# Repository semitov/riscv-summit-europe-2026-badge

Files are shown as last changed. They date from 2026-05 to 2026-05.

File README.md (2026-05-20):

# RISC-V Summit Europe 2026 Badge

Electronic badge PCB for RISC-V Summit Europe 2026 in Bologna, Italy. Designed in KiCad 10.

## Gallery

- Render of the badge on KiCad
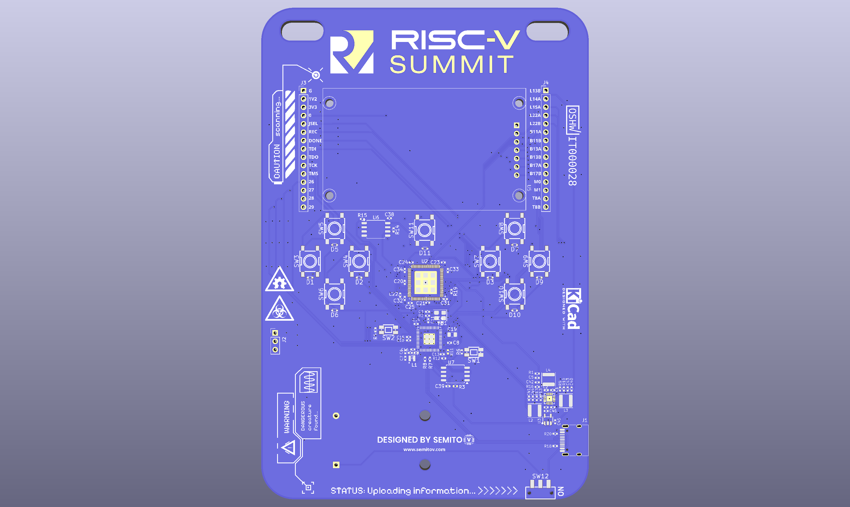
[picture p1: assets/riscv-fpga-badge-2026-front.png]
  
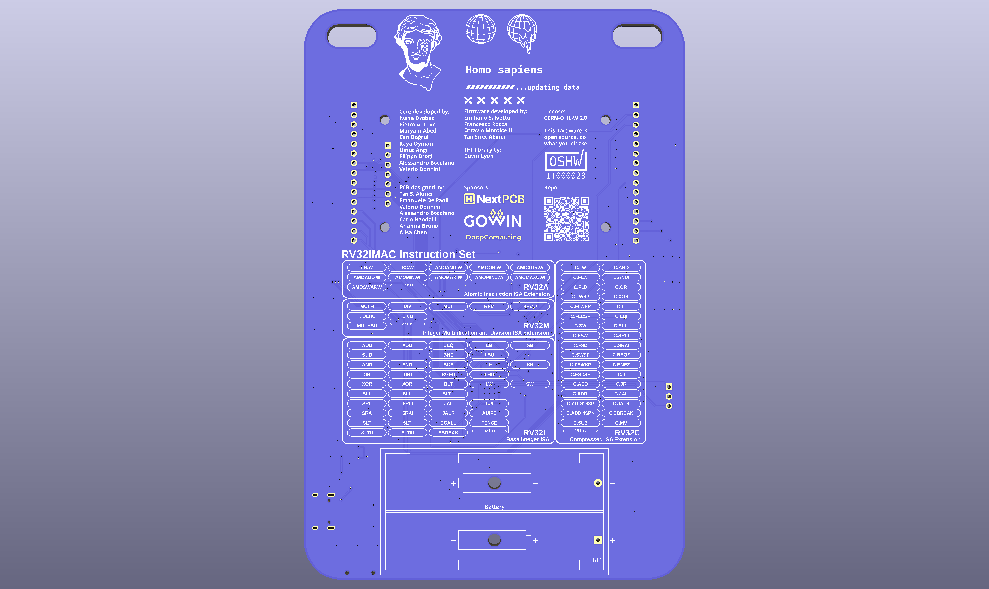
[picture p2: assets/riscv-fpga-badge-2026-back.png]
  

## License and Credits
Designed by: [Tan Siret Akıncı](https://github.com/tansiret), [Emanuele De Paoli](https://github.com/Irdyad), [Carlo Bendelli](https://github.com/CALIOSTRO7), [Valerio Donnini](https://github.com/Valerio-Donnini) and [Alessandro Bocchino](https://github.com/AleB-04).
This open source hardware project is licensed with [CERN-OHL-W](LICENSE). The project is sponsored by © 2026 [RISC-V International](), [NextPCB](https://www.nextpcb.com/), [GOWIN Semiconductor](https://www.gowinsemi.com/en/) and  [DeepComputing](https://deepcomputing.io/).
The project has been certified by [OSHWA](https://oshwa.org/) as Open Source Hardware (UID: [IT000028](https://certification.oshwa.org/it000028.html)).
</br>
<a href="https://certification.oshwa.org/it000028.html">
   
</a>

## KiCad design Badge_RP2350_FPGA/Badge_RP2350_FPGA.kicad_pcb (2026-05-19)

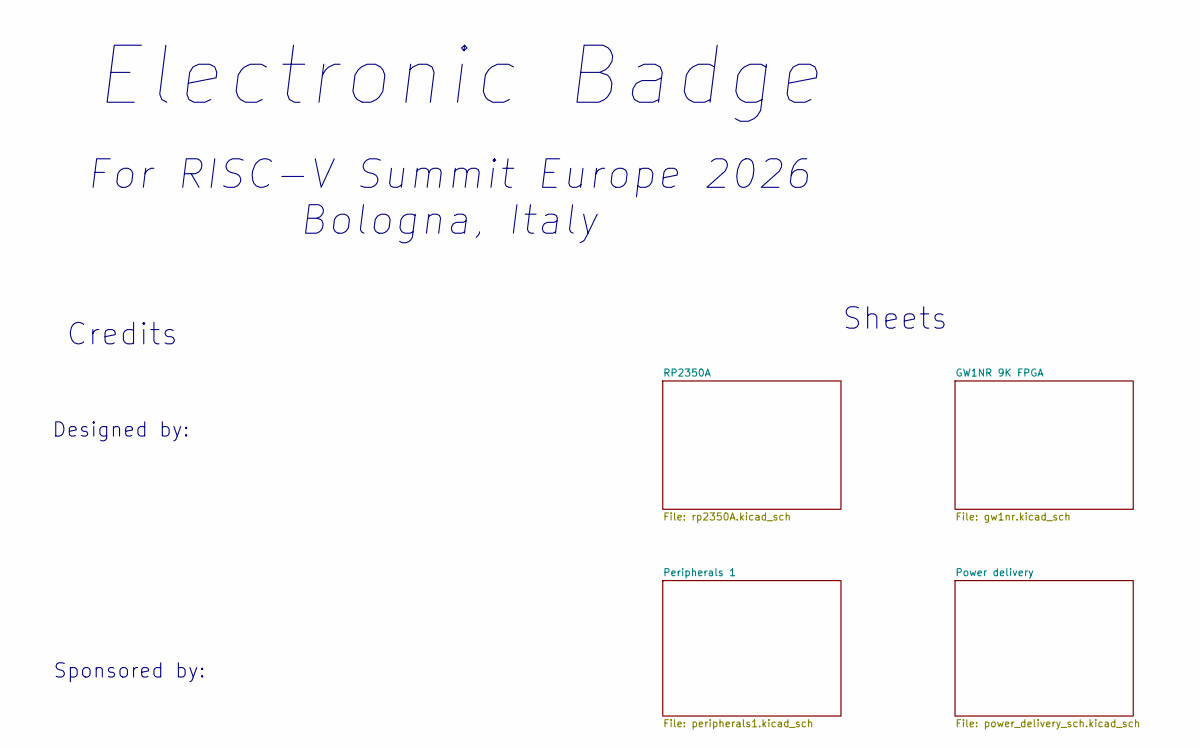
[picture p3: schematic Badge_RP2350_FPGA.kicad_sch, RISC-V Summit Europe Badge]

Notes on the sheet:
Sheets
Credits
Electronic Badge
Sponsored by:
For RISC-V Summit Europe 2026 Bologna, Italy
Designed by:

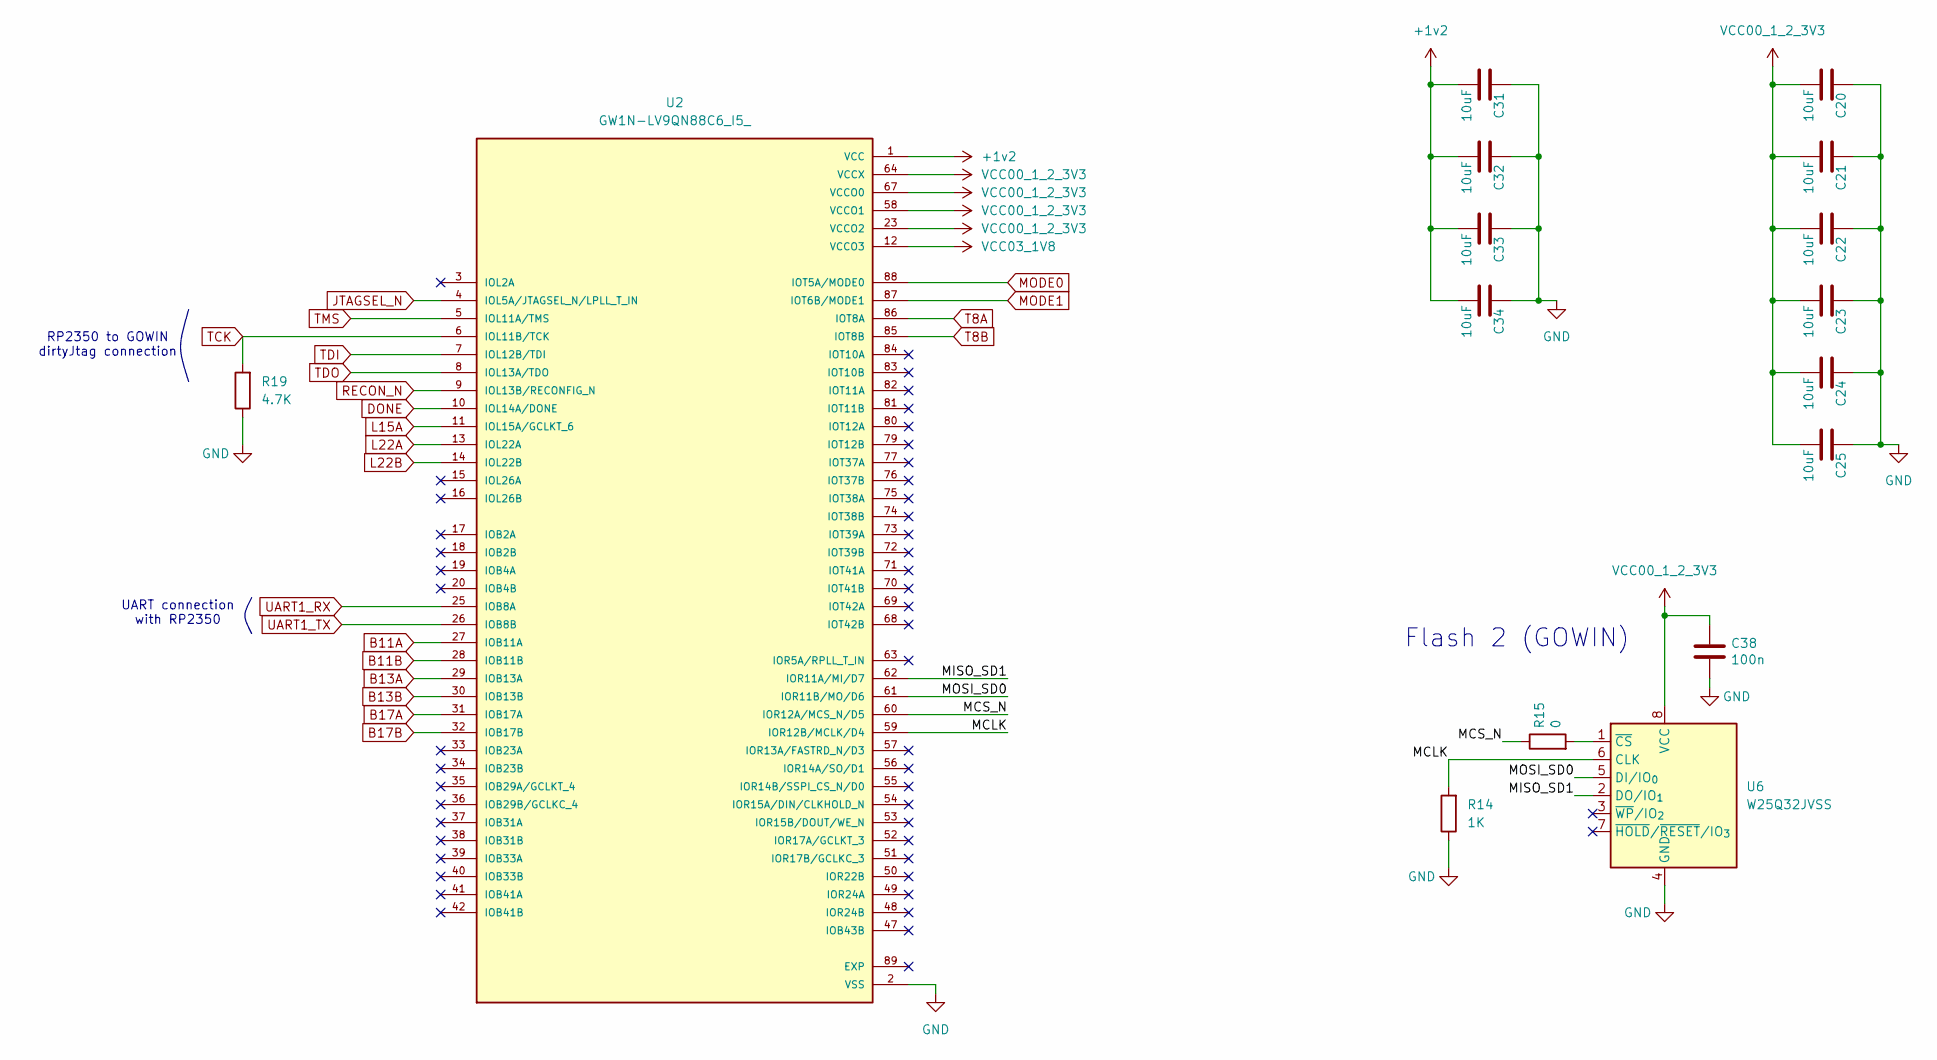
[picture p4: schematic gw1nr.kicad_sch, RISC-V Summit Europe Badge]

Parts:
C20, C21, C22, C23, C24, C25, C31, C32, C33, C34: 10uF; C_0402_1005Metric
C38: 100n; C_0402_1005Metric
R14: 1K; R_0402_1005Metric
R15: 0; R_0402_1005Metric
R19: 4.7K; R_0402_1005Metric
U2: GW1N-LV9QN88C6_I5_; QFN40P1000X1000X95-89N; PARTREV UG103-2.3E
U6: W25Q32JVSS; SOIC-8_5.3x5.3mm_P1.27mm

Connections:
/GW1NR 9K FPGA/MCLK: R14.2, U2.59 (IOR12B/MCLK/D4), U6.6 (CLK)
/GW1NR 9K FPGA/MCS_N: R15.1, U2.60 (IOR12A/MCS_N/D5)
/GW1NR 9K FPGA/MISO_SD1: U2.62 (IOR11A/MI/D7), U6.2 (DO/IO_{1})
/GW1NR 9K FPGA/MOSI_SD0: U2.61 (IOR11B/MO/D6), U6.5 (DI/IO_{0})
B11A: U2.27 (IOB11A); also elsewhere on the board
B11B: U2.28 (IOB11B); also elsewhere on the board
B13A: U2.29 (IOB13A); also elsewhere on the board
B13B: U2.30 (IOB13B); also elsewhere on the board
B17A: U2.31 (IOB17A); also elsewhere on the board
B17B: U2.32 (IOB17B); also elsewhere on the board
DONE: U2.10 (IOL14A/DONE); also elsewhere on the board
GND: C20.1, C21.1, C22.1, C23.1, C24.1, C25.1, C31.1, C32.1, C33.1, C34.1, C38.2, R14.1, R19.1, U2.2 (VSS), U2.21 (VSS), U2.24 (VSS), U2.43 (VSS), U2.46 (VSS), U2.65 (VSS), U6.4 (GND); also elsewhere on the board
JTAGSEL_N: U2.4 (IOL5A/JTAGSEL_N/LPLL_T_IN); also elsewhere on the board
L15A: U2.11 (IOL15A/GCLKT_6); also elsewhere on the board
L22A: U2.13 (IOL22A); also elsewhere on the board
L22B: U2.14 (IOL22B); also elsewhere on the board
MODE0: U2.88 (IOT5A/MODE0); also elsewhere on the board
MODE1: U2.87 (IOT6B/MODE1); also elsewhere on the board
unnamed: R15.2, U6.1 (~CS)
RECON_N: U2.9 (IOL13B/RECONFIG_N); also elsewhere on the board
T8A: U2.86 (IOT8A); also elsewhere on the board
T8B: U2.85 (IOT8B); also elsewhere on the board
TCK: R19.2, U2.6 (IOL11B/TCK); also elsewhere on the board
TDI: U2.7 (IOL12B/TDI); also elsewhere on the board
TDO: U2.8 (IOL13A/TDO); also elsewhere on the board
TMS: U2.5 (IOL11A/TMS); also elsewhere on the board
UART1_RX: U2.25 (IOB8A); also elsewhere on the board
UART1_TX: U2.26 (IOB8B); also elsewhere on the board
VCC00_1_2_3V3: C20.2, C21.2, C22.2, C23.2, C24.2, C25.2, C38.1, U2.23 (VCCO2), U2.44 (VCCO2), U2.58 (VCCO1), U2.64 (VCCX), U2.67 (VCCO0), U2.78 (VCCX), U6.8 (VCC); also elsewhere on the board
VCC03_1V8: U2.12 (VCCO3); also elsewhere on the board

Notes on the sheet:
RP2350 to GOWIN dirtyJtag connection
UART connection with RP2350
Flash 2 (GOWIN)

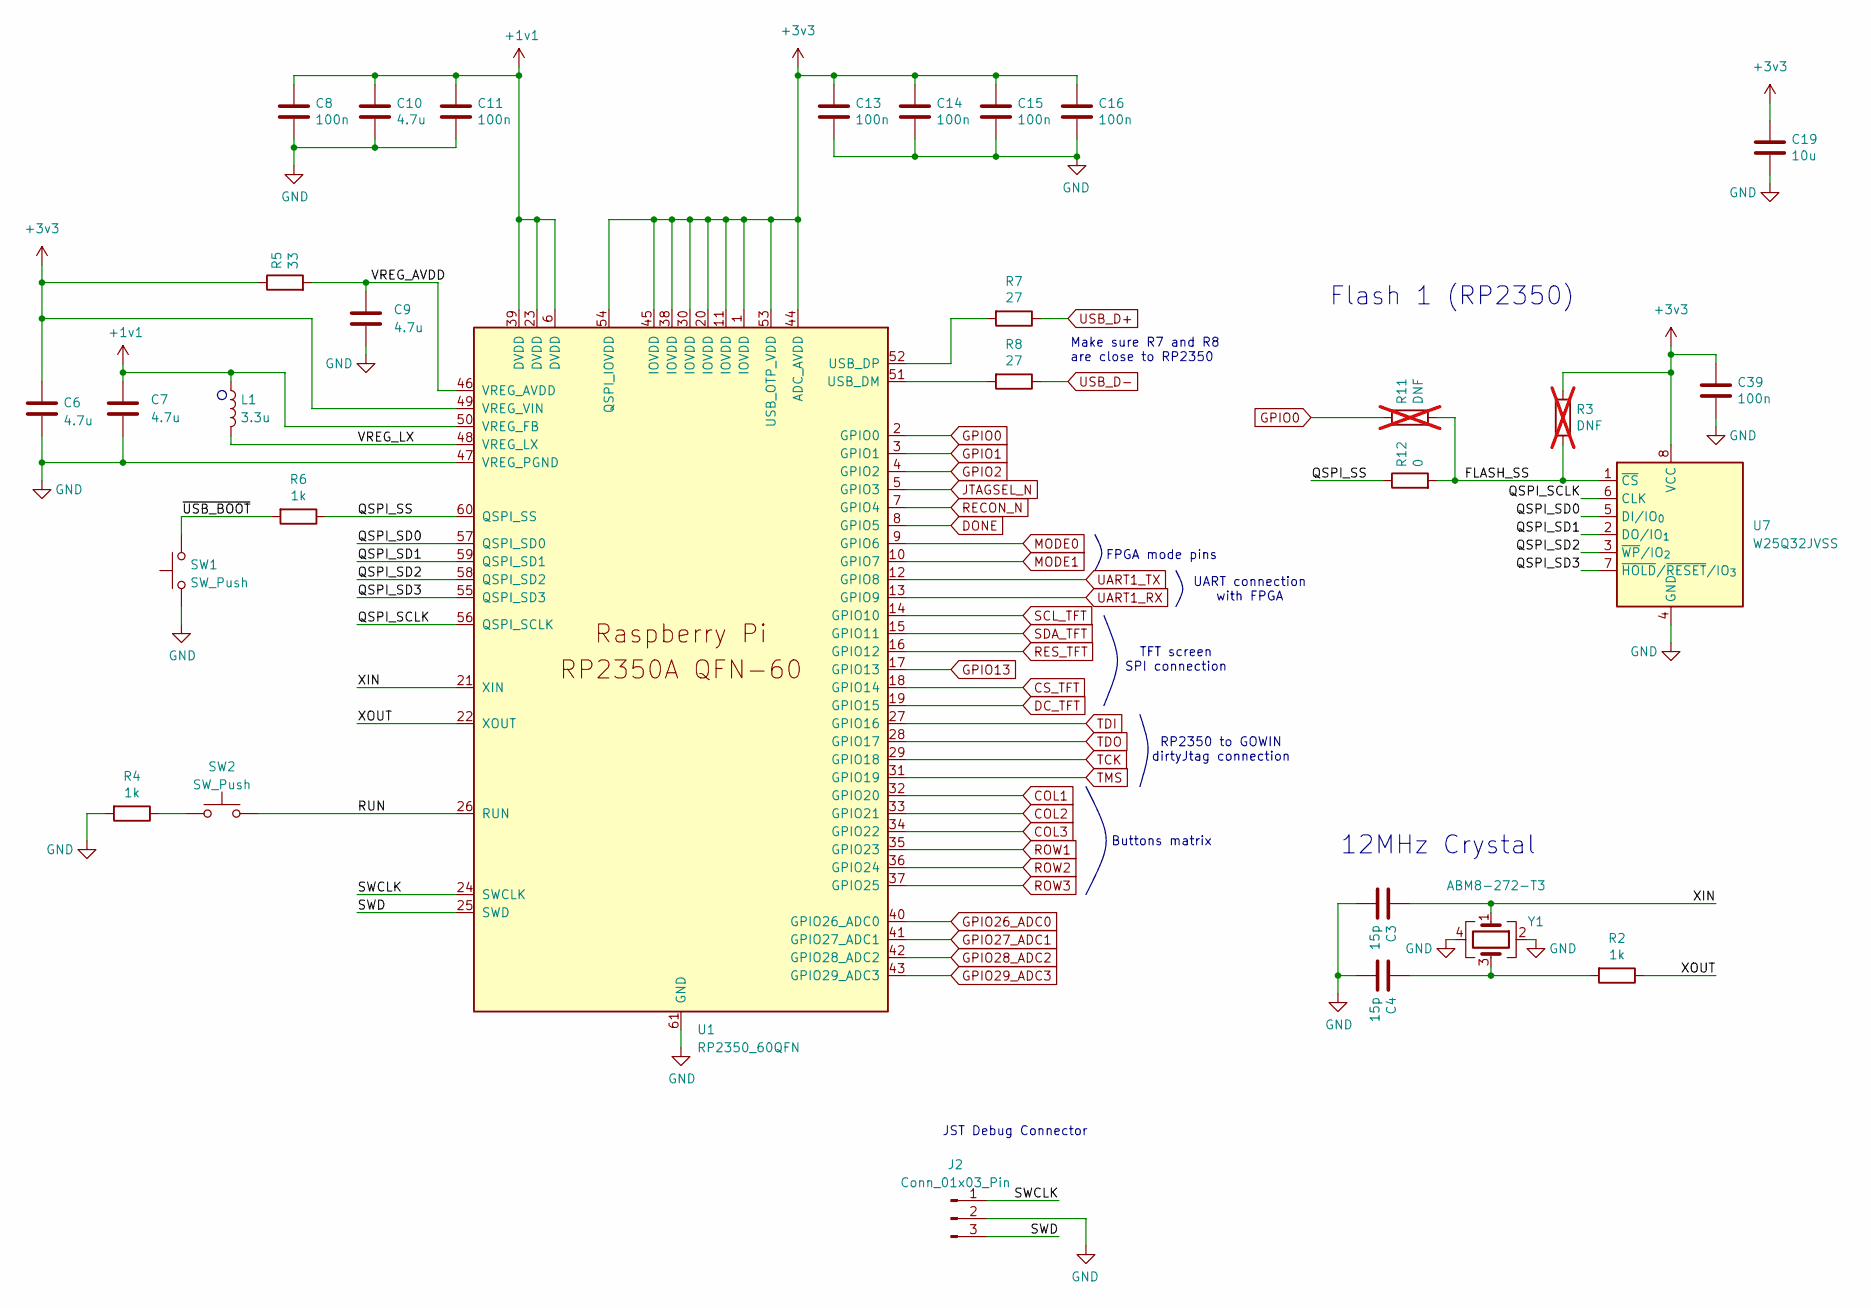
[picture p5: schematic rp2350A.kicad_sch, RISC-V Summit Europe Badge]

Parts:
C3, C4: 15p; C_0402_1005Metric
C6, C7, C9, C10: 4.7u; C_0402_1005Metric
C8, C11, C13, C14, C15, C16, C39: 100n; C_0402_1005Metric
C19: 10u; C_0805_2012Metric
J2: Conn_01x03_Pin; PinHeader_1x03_P2.54mm_Vertical
L1: 3.3u; L_pol_2016
R2, R4, R6: 1k; R_0402_1005Metric
R3, R11: DNF; R_0402_1005Metric; not fitted
R5: 33; R_0402_1005Metric
R7, R8: 27; R_0402_1005Metric
R12: 0; R_0402_1005Metric
SW1, SW2: SW_Push; C&K KMR621NGLFS
U1: RP2350_60QFN; RP2350-QFN-60-1EP_7x7_P0.4mm_EP3.4x3.4mm_ThermalVias
U7: W25Q32JVSS; SOIC-8_5.3x5.3mm_P1.27mm
Y1: ABM8-272-T3; Crystal_SMD_3225-4Pin_3.2x2.5mm

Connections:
+1v1: C7.1, C8.1, C10.1, C11.1, L1.1, U1.6 (DVDD), U1.23 (DVDD), U1.39 (DVDD), U1.50 (VREG_FB)
+3v3: C6.1, C13.1, C14.1, C15.1, C16.1, C19.1, C39.1, R3.1, R5.1, U1.1 (IOVDD), U1.11 (IOVDD), U1.20 (IOVDD), U1.30 (IOVDD), U1.38 (IOVDD), U1.44 (ADC_AVDD), U1.45 (IOVDD), U1.49 (VREG_VIN), U1.53 (USB_OTP_VDD), U1.54 (QSPI_IOVDD), U7.8 (VCC); also elsewhere on the board
/RP2350A/FLASH_SS: R3.2, R11.2, R12.2, U7.1 (~CS)
/RP2350A/QSPI_SCLK: U1.56 (QSPI_SCLK), U7.6 (CLK)
/RP2350A/QSPI_SD0: U1.57 (QSPI_SD0), U7.5 (DI/IO_{0})
/RP2350A/QSPI_SD1: U1.59 (QSPI_SD1), U7.2 (DO/IO_{1})
/RP2350A/QSPI_SD2: U1.58 (QSPI_SD2), U7.3 (~WP/IO_{2})
/RP2350A/QSPI_SD3: U1.55 (QSPI_SD3), U7.7 (~HOLD/~RESET/IO_{3})
/RP2350A/QSPI_SS: R6.1, R12.1, U1.60 (QSPI_SS)
/RP2350A/RUN: SW2.2, U1.26 (RUN)
/RP2350A/SWCLK: J2.1, U1.24 (SWCLK)
/RP2350A/SWD: J2.3, U1.25 (SWD)
/RP2350A/VREG_AVDD: C9.1, R5.2, U1.46 (VREG_AVDD)
/RP2350A/VREG_LX: L1.2, U1.48 (VREG_LX)
/RP2350A/XIN: C3.1, U1.21 (XIN), Y1.1
/RP2350A/XOUT: R2.1, U1.22 (XOUT)
/RP2350A/~USB_BOOT: R6.2, SW1.2
COL1: U1.32 (GPIO20); also elsewhere on the board
COL2: U1.33 (GPIO21); also elsewhere on the board
COL3: U1.34 (GPIO22); also elsewhere on the board
CS_TFT: U1.18 (GPIO14); also elsewhere on the board
DC_TFT: U1.19 (GPIO15); also elsewhere on the board
DONE: U1.8 (GPIO5); also elsewhere on the board
GND: C3.2, C4.2, C6.2, C7.2, C8.2, C9.2, C10.2, C11.2, C13.2, C14.2, C15.2, C16.2, C19.2, C39.2, J2.2, R4.2, SW1.1, U1.47 (VREG_PGND), U1.61 (GND), U7.4 (GND), Y1.2, Y1.4; also elsewhere on the board
GPIO0: R11.1, U1.2 (GPIO0); also elsewhere on the board
GPIO1: U1.3 (GPIO1)
GPIO2: U1.4 (GPIO2)
GPIO13: U1.17 (GPIO13)
GPIO26_ADC0: U1.40 (GPIO26_ADC0); also elsewhere on the board
GPIO27_ADC1: U1.41 (GPIO27_ADC1); also elsewhere on the board
GPIO28_ADC2: U1.42 (GPIO28_ADC2); also elsewhere on the board
GPIO29_ADC3: U1.43 (GPIO29_ADC3); also elsewhere on the board
JTAGSEL_N: U1.5 (GPIO3); also elsewhere on the board
MODE0: U1.9 (GPIO6); also elsewhere on the board
MODE1: U1.10 (GPIO7); also elsewhere on the board
unnamed: C4.1, R2.2, Y1.3
unnamed: R4.1, SW2.1
unnamed: R8.2, U1.51 (USB_DM)
unnamed: R7.2, U1.52 (USB_DP)
RECON_N: U1.7 (GPIO4); also elsewhere on the board
RES_TFT: U1.16 (GPIO12); also elsewhere on the board
ROW1: U1.35 (GPIO23); also elsewhere on the board
ROW2: U1.36 (GPIO24); also elsewhere on the board
ROW3: U1.37 (GPIO25); also elsewhere on the board
SCL_TFT: U1.14 (GPIO10); also elsewhere on the board
SDA_TFT: U1.15 (GPIO11); also elsewhere on the board
TCK: U1.29 (GPIO18); also elsewhere on the board
TDI: U1.27 (GPIO16); also elsewhere on the board
TDO: U1.28 (GPIO17); also elsewhere on the board
TMS: U1.31 (GPIO19); also elsewhere on the board
UART1_RX: U1.13 (GPIO9); also elsewhere on the board
UART1_TX: U1.12 (GPIO8); also elsewhere on the board
USB_D+: R7.1; also elsewhere on the board
USB_D-: R8.1; also elsewhere on the board

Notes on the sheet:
Flash 1 (RP2350)
JST Debug Connector
Make sure R7 and R8 are close to RP2350
TFT screen SPI connection
FPGA mode pins
UART connection with FPGA
Buttons matrix
RP2350 to GOWIN dirtyJtag connection
12MHz Crystal

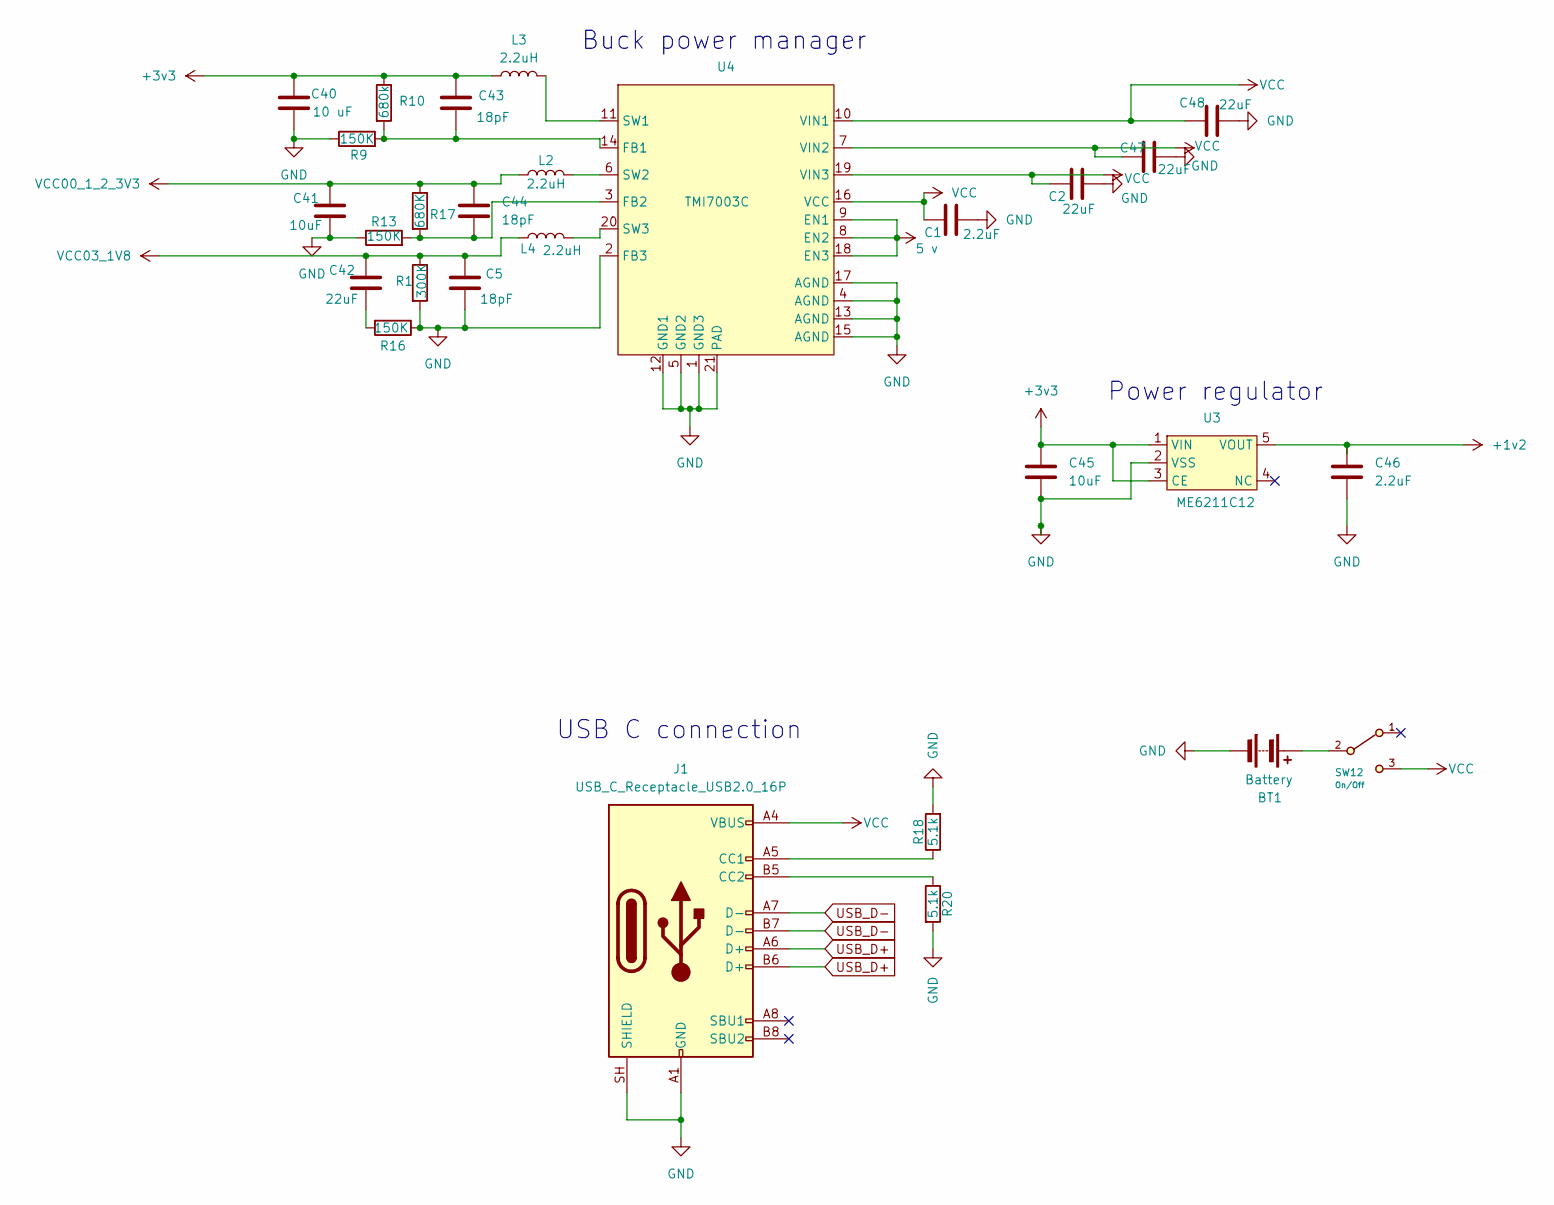
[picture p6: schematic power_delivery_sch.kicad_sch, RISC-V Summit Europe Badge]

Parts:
BT1: Battery; BatteryHolder_Keystone_2462_2xAA
C1, C46: 2.2uF; C_0402_1005Metric
C2, C42, C47, C48: 22uF; C_0402_1005Metric
C5, C43, C44: 18pF; C_0402_1005Metric
C40: 10 uF; C_0402_1005Metric
C41, C45: 10uF; C_0402_1005Metric
J1: USB_C_Receptacle_USB2.0_16P; USB_C_Receptacle_HRO_TYPE-C-31-M-12
L2, L3, L4: 2.2uH; L_APV_ANR4018
R1: 300K; R_0402_1005Metric
R9, R13, R16: 150K; R_0402_1005Metric
R10: 680k; R_0402_1005Metric
R17: 680K; R_0402_1005Metric
R18, R20: 5.1k; R_0402_1005Metric
SW12: On/Off; C&K JS102011SAQN
U3: ME6211C12; SOT-23-5_L3.0-W1.7-P0.95-LS2.8-BL
U4: TMI7003C; QFN-20_L3.0-W3.0-P0.40-BL-EP1.7

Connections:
5 v: U4.8 (EN2), U4.9 (EN1), U4.18 (EN3)
+3v3: C40.1, C43.1, C45.1, L3.1, R10.1, U3.1 (VIN), U3.3 (CE); also elsewhere on the board
GND: BT1.2 (-), C1.2, C2.2, C5.2, C40.2, C41.2, C45.2, C46.2, C47.2, C48.2, J1.A1 (GND), J1.A12 (GND), J1.B1 (GND), J1.B12 (GND), J1.SH (SHIELD), R1.2, R9.1, R13.1, R16.1, R18.2, R20.2, U3.2 (VSS), U4.1 (GND3), U4.2 (FB3), U4.4 (AGND), U4.5 (GND2), U4.12 (GND1), U4.13 (AGND), U4.15 (AGND), U4.17 (AGND), U4.21 (PAD); also elsewhere on the board
unnamed: BT1.1 (+), SW12.2 (B)
unnamed: C42.2, R16.2
unnamed: J1.A5 (CC1), R18.1
unnamed: J1.B5 (CC2), R20.1
unnamed: C43.2, R9.2, R10.2, U4.14 (FB1)
unnamed: C44.2, R13.2, R17.2, U4.3 (FB2)
unnamed: L3.2, U4.11 (SW1)
unnamed: L2.2, U4.6 (SW2)
unnamed: L4.2, U4.20 (SW3)
USB_D+: J1.A6 (D+), J1.B6 (D+); also elsewhere on the board
USB_D-: J1.A7 (D-), J1.B7 (D-); also elsewhere on the board
VCC00_1_2_3V3: C41.1, C44.1, L2.1, R17.1; also elsewhere on the board
VCC03_1V8: C5.1, C42.1, L4.1, R1.1; also elsewhere on the board

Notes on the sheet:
Power regulator
USB C connection
Buck power manager

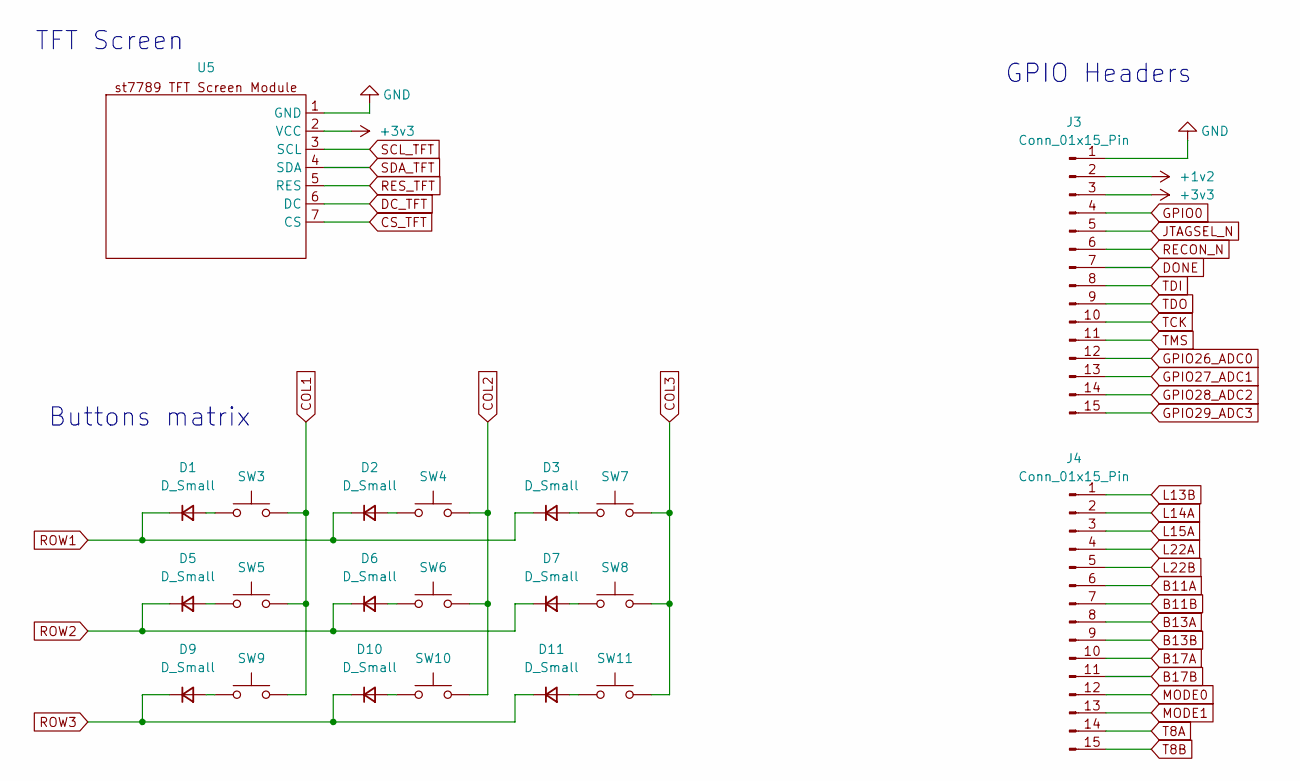
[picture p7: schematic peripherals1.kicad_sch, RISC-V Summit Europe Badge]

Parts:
D1, D2, D3, D5, D6, D7, D9, D10, D11: D_Small; Nexperia BAS516,115
J3, J4: Conn_01x15_Pin; PinHeader_1x15_P2.54mm_Vertical
SW3, SW4, SW5, SW6, SW7, SW8, SW9, SW10, SW11: SHOU HAN TS665PA 250gf
U5: st7789_7pin_noblk

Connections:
+3v3: J3.3, U5.2 (VCC); also elsewhere on the board
B11A: J4.6; also elsewhere on the board
B11B: J4.7; also elsewhere on the board
B13A: J4.8; also elsewhere on the board
B13B: J4.9; also elsewhere on the board
B17A: J4.10; also elsewhere on the board
B17B: J4.11; also elsewhere on the board
COL1: SW3.2, SW5.2, SW9.2; also elsewhere on the board
COL2: SW4.2, SW6.2, SW10.2; also elsewhere on the board
COL3: SW7.2, SW8.2, SW11.2; also elsewhere on the board
CS_TFT: U5.7 (CS); also elsewhere on the board
DC_TFT: U5.6 (DC); also elsewhere on the board
DONE: J3.7; also elsewhere on the board
GND: J3.1, U5.1 (GND); also elsewhere on the board
GPIO0: J3.4; also elsewhere on the board
GPIO26_ADC0: J3.12; also elsewhere on the board
GPIO27_ADC1: J3.13; also elsewhere on the board
GPIO28_ADC2: J3.14; also elsewhere on the board
GPIO29_ADC3: J3.15; also elsewhere on the board
JTAGSEL_N: J3.5; also elsewhere on the board
L13B: J4.1
L14A: J4.2
L15A: J4.3; also elsewhere on the board
L22A: J4.4; also elsewhere on the board
L22B: J4.5; also elsewhere on the board
MODE0: J4.12; also elsewhere on the board
MODE1: J4.13; also elsewhere on the board
unnamed: D1.2 (A), SW3.1
unnamed: D2.2 (A), SW4.1
unnamed: D3.2 (A), SW7.1
unnamed: D5.2 (A), SW5.1
unnamed: D6.2 (A), SW6.1
unnamed: D7.2 (A), SW8.1
unnamed: D9.2 (A), SW9.1
unnamed: D10.2 (A), SW10.1
unnamed: D11.2 (A), SW11.1
RECON_N: J3.6; also elsewhere on the board
RES_TFT: U5.5 (RES); also elsewhere on the board
ROW1: D1.1 (K), D2.1 (K), D3.1 (K); also elsewhere on the board
ROW2: D5.1 (K), D6.1 (K), D7.1 (K); also elsewhere on the board
ROW3: D9.1 (K), D10.1 (K), D11.1 (K); also elsewhere on the board
SCL_TFT: U5.3 (SCL); also elsewhere on the board
SDA_TFT: U5.4 (SDA); also elsewhere on the board
T8A: J4.14; also elsewhere on the board
T8B: J4.15; also elsewhere on the board
TCK: J3.10; also elsewhere on the board
TDI: J3.8; also elsewhere on the board
TDO: J3.9; also elsewhere on the board
TMS: J3.11; also elsewhere on the board

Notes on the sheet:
Buttons matrix
TFT Screen
GPIO Headers

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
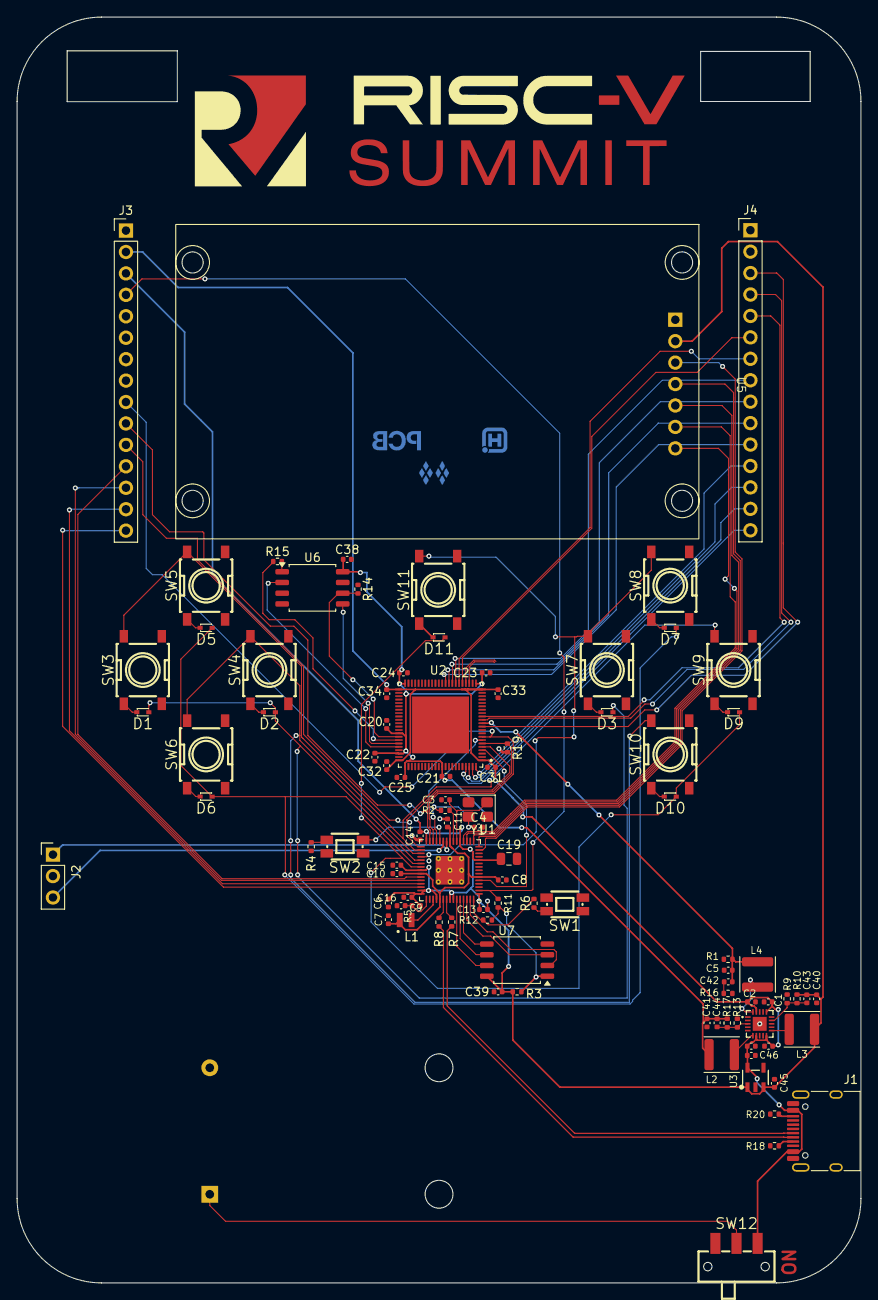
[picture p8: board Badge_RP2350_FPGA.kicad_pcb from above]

Board: 2 copper layers, 100.0 x 150.0 mm, 95 parts (1 on the bottom side), 89 nets.

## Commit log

2026-03-30 initial commit - very basic work done so far
    [Badge_RP2350_FPGA.kicad_pcb, Badge_RP2350_FPGA.kicad_sch, gw1nr.kicad_sch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]
2026-04-08 add new schematic and footprint element (subject for verification, and edit schematics a bit
    [peripherals1.kicad_sch]
2026-04-09 add jtag connection
    [gw1nr.kicad_sch, rp2350A.kicad_sch]
2026-04-09 edit custom st7789 footprint
    [peripherals1.kicad_sch]
2026-04-14 add buttons by Arianna and make Flash 2 shared between 2 chips
    [gw1nr.kicad_sch, peripherals1.kicad_sch, rp2350A.kicad_sch]
2026-05-02 add power delivery by Carlo
    [Badge_RP2350_FPGA.kicad_sch, power_delivery_sch.kicad_sch]
2026-05-04 add type c port and uart connections
    [Badge_RP2350_FPGA.kicad_sch, gw1nr.kicad_sch, peripherals1.kicad_sch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]
2026-05-04 modify usb and flash connections
    [Badge_RP2350_FPGA.kicad_sch, gw1nr.kicad_sch, peripherals1.kicad_sch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]
2026-05-05 edit schematics, add global pins
    [Badge_RP2350_FPGA.kicad_sch, gw1nr.kicad_sch, peripherals1.kicad_sch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]
2026-05-06 assign all footprints and import to pcb
    [Badge_RP2350_FPGA.kicad_pcb, gw1nr.kicad_sch, peripherals1.kicad_sch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]
2026-05-06 started PCB layout
    [Badge_RP2350_FPGA.kicad_pcb]
2026-05-06 add headers and fix voltage references
    [Badge_RP2350_FPGA.kicad_pcb, Badge_RP2350_FPGA.kicad_sch, gw1nr.kicad_sch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]
2026-05-06 add x to unused pins and connect more pins
    [Badge_RP2350_FPGA.kicad_pcb, gw1nr.kicad_sch]
2026-05-08 add jtagsel_n connection
    [Badge_RP2350_FPGA.kicad_sch, gw1nr.kicad_sch, peripherals1.kicad_sch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]
2026-05-08 add more FPGA connections and generate netlist, bom
    [Badge_RP2350_FPGA.csv, gw1nr.kicad_sch, peripherals1.kicad_sch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]
2026-05-11 update footprints, connections, some labels and more
    [Badge_RP2350_FPGA.kicad_pcb, Badge_RP2350_FPGA.kicad_sch, gw1nr.kicad_sch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]
2026-05-13 add PCB silkscreen-copper art
    [Badge_RP2350_FPGA.kicad_pcb]
2026-05-14 edit schematics visually and edit pcb
    [Badge_RP2350_FPGA.csv, Badge_RP2350_FPGA.kicad_pcb, Badge_RP2350_FPGA.kicad_sch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]
2026-05-14 edit pcb placement slightly
    [Badge_RP2350_FPGA.kicad_pcb]
2026-05-15 M: pcb routing start, minor schematic changes
    [Badge_RP2350_FPGA.kicad_pcb, gw1nr.kicad_sch, power_delivery_sch.kicad_sch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]
2026-05-18 Routing progress
    [Badge_RP2350_FPGA.kicad_pcb]
2026-05-18 Update PCB routing
    [Badge_RP2350_FPGA.kicad_pcb]
2026-05-19 U: PCB routing
    [Badge_RP2350_FPGA.kicad_pcb]
2026-05-19 finalize the design, add photos
    [Badge_RP2350_FPGA.kicad_sch, gw1nr.kicad_sch, peripherals1.kicad_sch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]
2026-05-20 M: better GND coverage, fixed floating net
2026-05-20 generate gerbers
    [Badge_RP2350_FPGA-CuBottom.gbr, Badge_RP2350_FPGA-CuTop.gbr, Badge_RP2350_FPGA-EdgeCuts.gbr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]
2026-05-20 F: DRC and USB-C
    [power_delivery_sch.kicad_sch]
2026-05-20 edit pcb and generate gerber files, centroid file
    [Badge_RP2350_FPGA-B_Cu.gbr, Badge_RP2350_FPGA-B_Mask.gbr, Badge_RP2350_FPGA-B_Paste.gbr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]
2026-05-20 add OSHWA UID IT000028
    [Badge_RP2350_FPGA-B_Cu.gbr, Badge_RP2350_FPGA-B_Mask.gbr, Badge_RP2350_FPGA-B_Paste.gbr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]
2026-05-21 edit silkscreen etc
    [Badge_RP2350_FPGA-B_Cu.gbr, Badge_RP2350_FPGA-B_Mask.gbr, Badge_RP2350_FPGA-B_Paste.gbr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]

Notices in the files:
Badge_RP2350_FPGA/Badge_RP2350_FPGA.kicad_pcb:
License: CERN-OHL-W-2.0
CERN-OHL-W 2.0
